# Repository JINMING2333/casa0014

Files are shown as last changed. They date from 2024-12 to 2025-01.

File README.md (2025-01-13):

# casa0014_LumiHealth
A device to monitor the health statues of users and create a comfortable light environment for them.
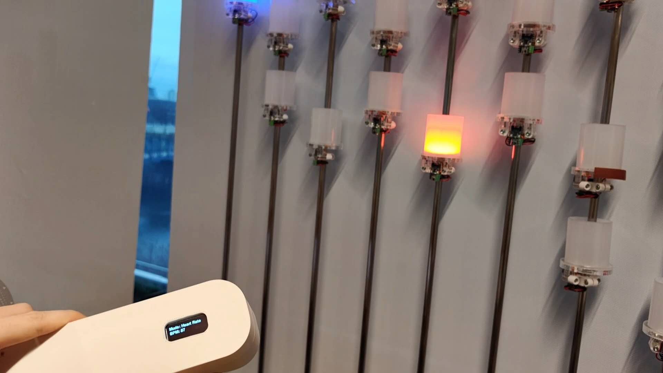
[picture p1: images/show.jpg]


## Inspiration
In the IoT market, smart home devices and wearable medical equipment have always been among the most popular areas. My design philosophy has always been centered on a people-oriented approach. A successful IoT device not only presents technical challenges but also requires careful consideration of social and user needs. During lectures, I learned that IoT devices can improve our quality of life in countless ways. However, the current IoT market has not met expectations or reached its full potential. I believe this is because many products fail to integrate seamlessly into people's daily lives and lack a truly user-centered design.

<table>
  <tr>
    <td align="center" width="33%">
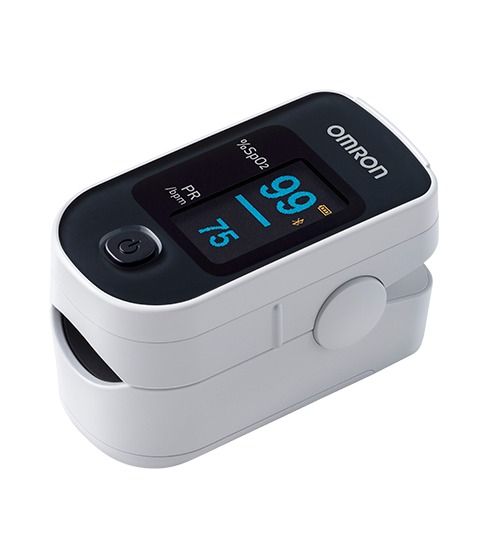
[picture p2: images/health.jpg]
Blood oxygen monitor
      <br/>
      <em>Fig.1 Blood oxygen monitor</em>
    </td>
    <td align="center" width="33%">
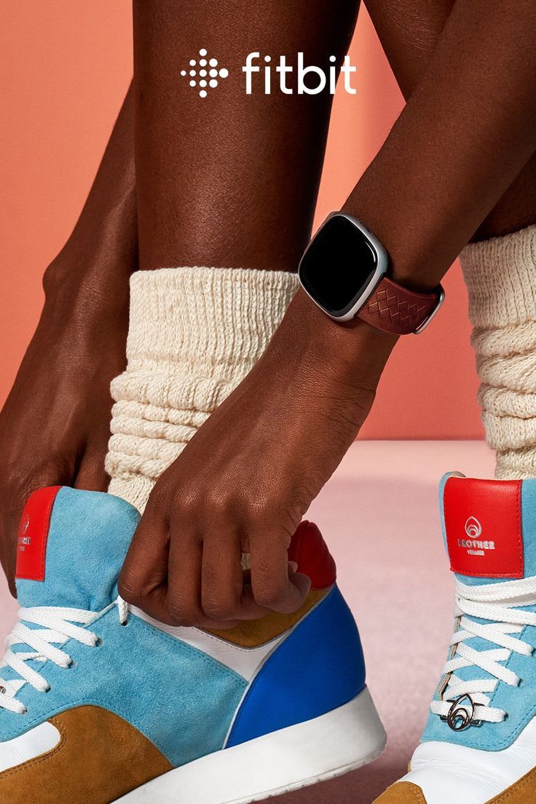
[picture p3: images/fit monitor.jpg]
Sports bracelet
      <br/>
      <em>Fig.2 Sports bracelet</em>
    </td>
    <td align="center" width="33%">
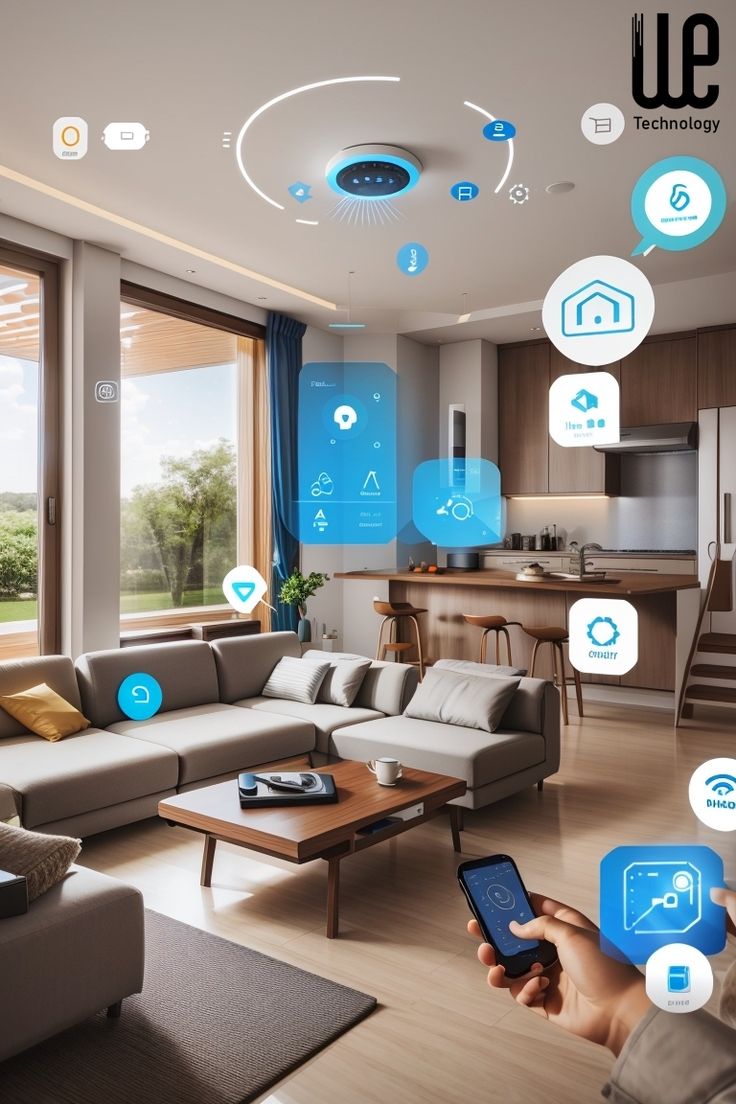
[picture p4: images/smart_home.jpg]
Smart Home Device
      <br/>
      <em>Fig.3 Smart Home Device</em>
    </td>
  </tr>
</table>

An IoT device, no matter how advanced its technological capabilities, cannot fulfill its purpose if users find it difficult or unappealing to use. This insight inspired me to design Lumi_Health, a health monitoring and environmental optimization system. Lumi_Health is dedicated to keeping users at the core of its design, aiming to enhance user experiences and improve quality of life through simplicity and accessibility.

### Current Application Scenarios
1) Medical Assistance
   Used for data collection and remote monitoring, when the patient's heart rate exceeds the normal threshold, the LED lights up red to alarm.
2) Fitness Tracking
   Use LED to indicate exercise intensity, such as blue means need to increase exercise intensity and red means reduce it.
3) Emotion Regulation
   Create a soothing environment through warm and cool tones or breathing light effects to help users relax.

## Design modes
1) Health status monitor mode: LED color changes can reflect different heart rate ranges.
   1) Blue indicates a lower heart rate(40-60 BPM).
   2) Yellow indicates a normal heart rate(60-85 BPM).
   3) Red indicates a high heart rate(85-120 BPM).
2) Relaxation mode: Adjust the lighting according to different body temperature ranges to create a relaxing atmosphere.
   1) when temperature is low, LED shows warm color breathing effect. 
   2) When temperature is high, LED shows cool color breathing effect;
   
PS: Switch mode by taping the surface of the sensor(when my finger approaches the sensor, the infrared reflection value changes greatly).

## System architecture
The operation of the whole project:
1) Make ensure the operating environment(connect WIFI and MQTT) is set up first;
2) Select the mode;
3) Read the data through the sensor, and then run different functions under the corresponding mode;
4) Publish and subscribe pixel topics through MQTT, update the light status, and realize remote operation.

MAX30102 sensor -> Arduino MKR 1010 -> WIFI -> MQTT broker -> LEDs

# Hardware settings
## Components

<table>
  <tr>
    <th width="15%">Component</th>
    <th width="20%">Image</th>
    <th width="25%">Function</th>
    <th width="25%">Wiring</th>
    <th width="15%">Library</th>
  </tr>
  <tr>
    <td>MAX30102 Sensor</td>
    <td align="center">
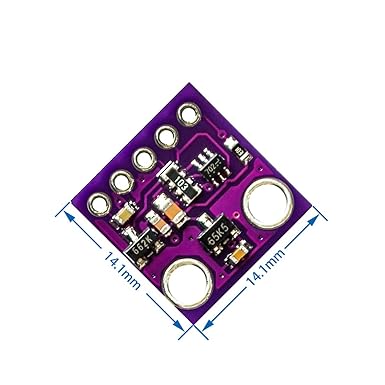
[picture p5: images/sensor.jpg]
MAX30102 Sensor
      
    </td>
    <td>
      - Heart rate monitoring<br/>
      - Blood oxygen level detection<br/>
      - Temperature sensing<br/>
      - IR reflection value measurement
    </td>
    <td>
      - VIN → 3.3V<br/>
      - GND → GND<br/>
      - SCL → SCL<br/>
      - SDA → SDA
    </td>
    <td>
      - SparkFun MAX3010x library<br/>
      - Wire.h
    </td>
  </tr>
  <tr>
    <td>OLED Display</td>
    <td align="center">
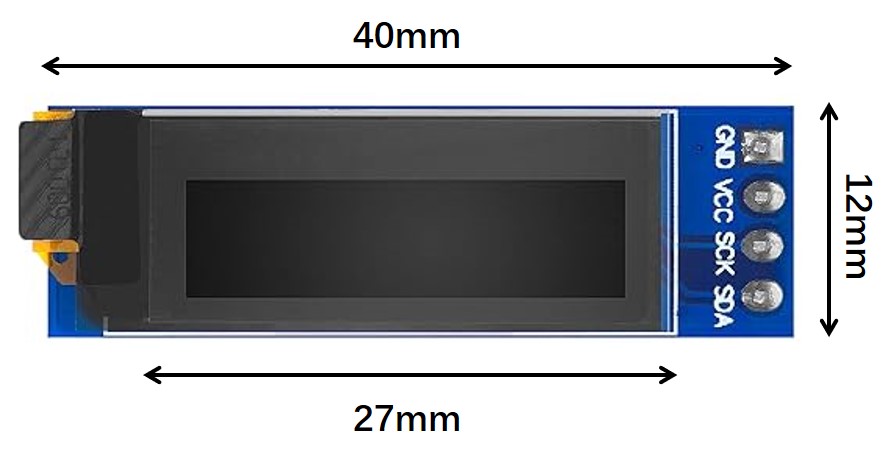
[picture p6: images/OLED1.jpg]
OLED Display
      
    </td>
    <td>
      - Real-time data display<br/>
      - Mode status indication<br/>
    </td>
    <td>
      - VCC → 3.3V<br/>
      - GND → GND<br/>
      - SCL → SCL<br/>
      - SDA → SDA
    </td>
    <td>
      - Adafruit_SSD1306<br/>
      - Adafruit_GFX
    </td>
  </tr>
</table>

## Wiring
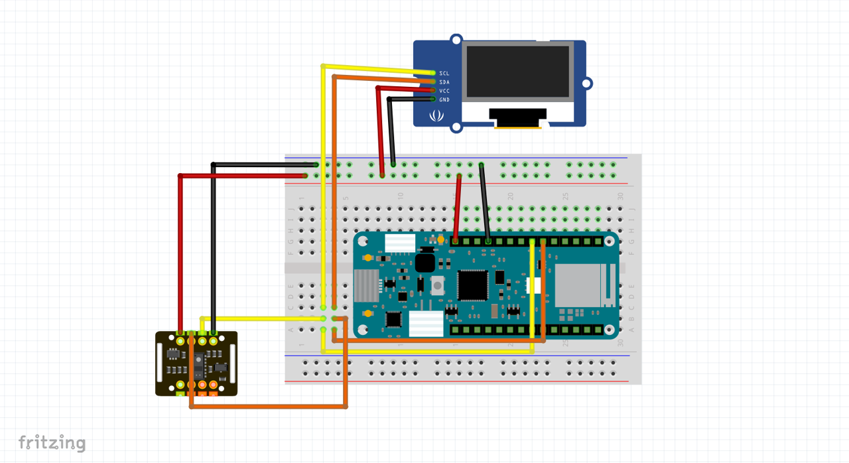
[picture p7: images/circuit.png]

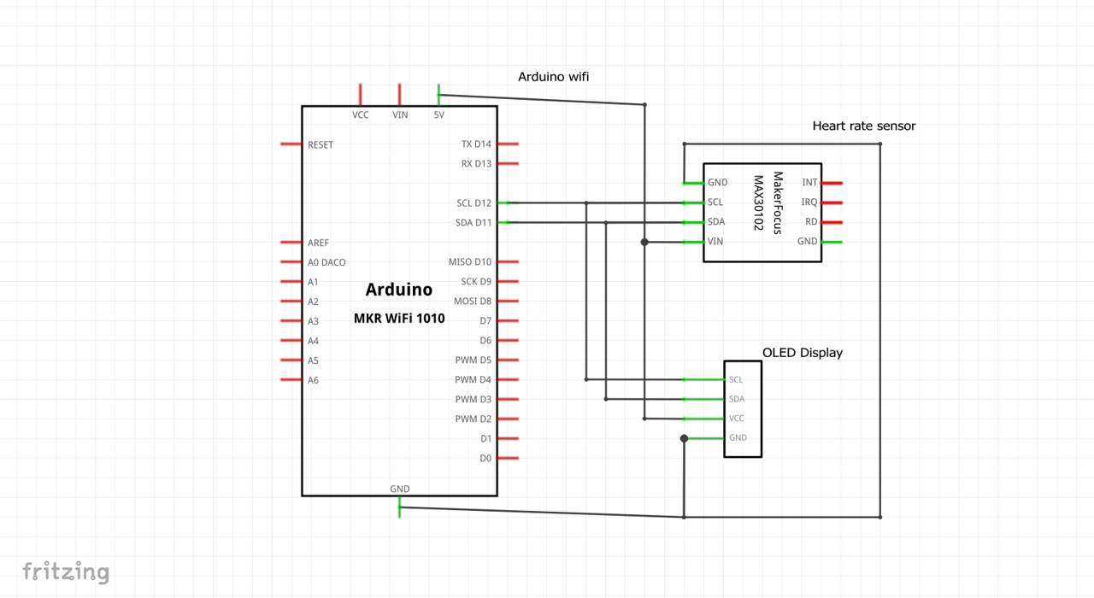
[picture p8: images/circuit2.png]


## Enclosure
The development of the device's casing was also an iterative process. During the early testing phase, a permanent casing was unnecessary and would have hindered quick adjustments and design iterations. Therefore, I initially used simple cardboard boxes as makeshift casings to facilitate rapid prototyping and modifications.

<table>
  <tr>
    <td align="center" width="33%">
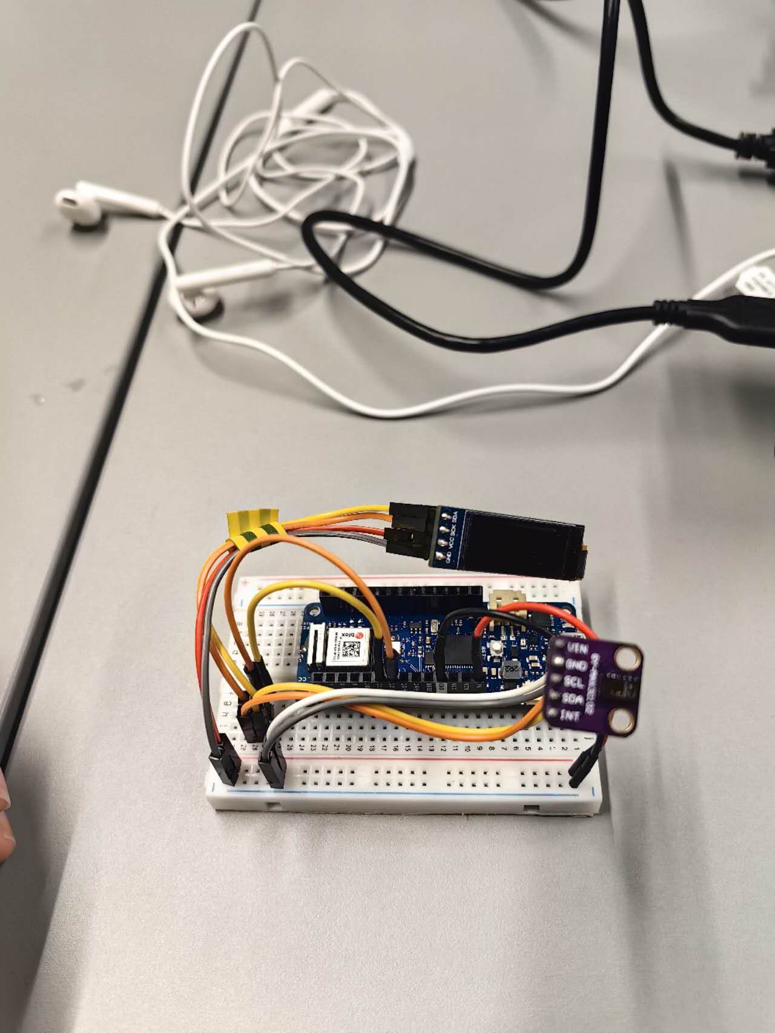
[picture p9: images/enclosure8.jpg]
      
    </td>
    <td align="center" width="33%">
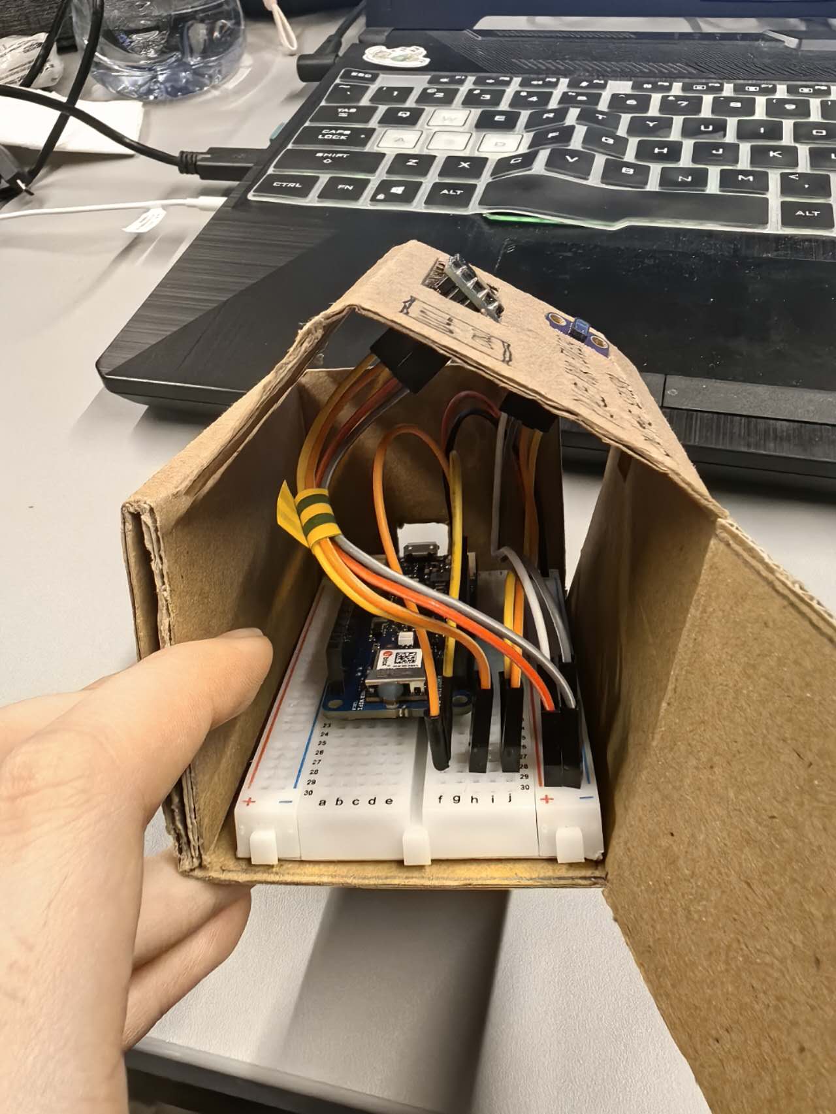
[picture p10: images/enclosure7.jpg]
      
    </td>
    <td align="center" width="33%">
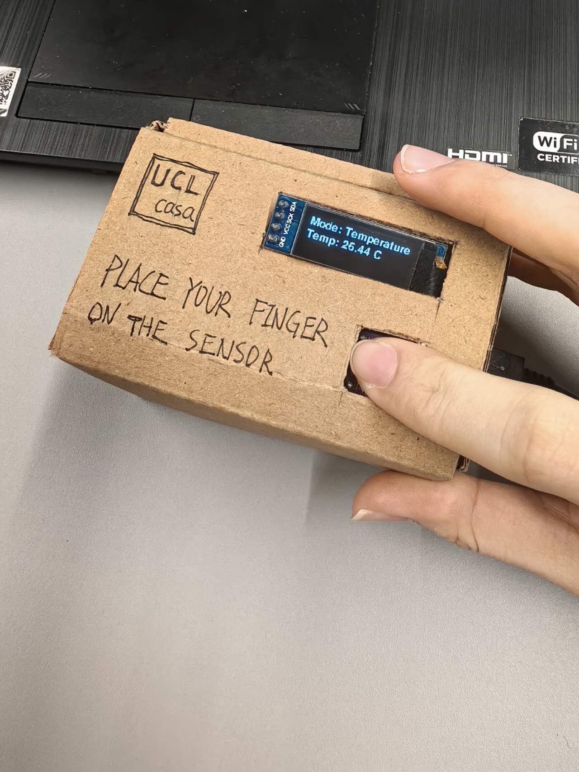
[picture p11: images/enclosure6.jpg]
      
    </td>
  </tr>
</table>
<p align="center"><em>simple cardboard box</em></p>

As the project progressed and the functions stabilized, it became time to formally consider the casing design. Drawing inspiration from the sleek and ergonomic form of a thermometer, I began creating a modeled design that balanced aesthetics, usability, and practicality. This approach ensured the final casing not only complemented the device’s functionality but also provided a user-friendly experience.

<table>
  <tr>
    <td align="center" width="25%">
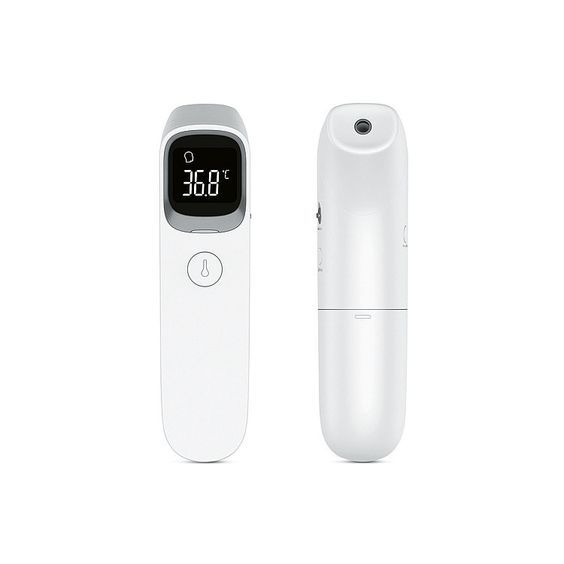
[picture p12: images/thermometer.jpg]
      <br/>
      <em>Fig.1 Inspiration-Thermometer</em>
    </td>
    <td align="center" width="25%">
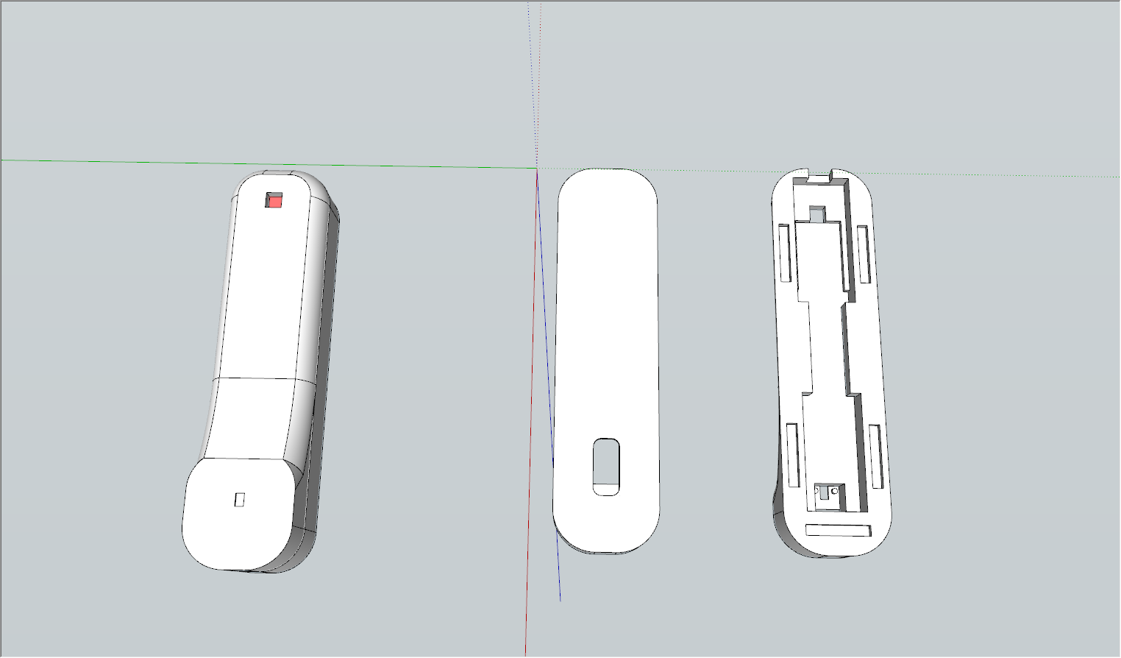
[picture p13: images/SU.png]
      <br/>
      <em>Fig.2 3D Model</em>
    </td>
    <td align="center" width="25%">
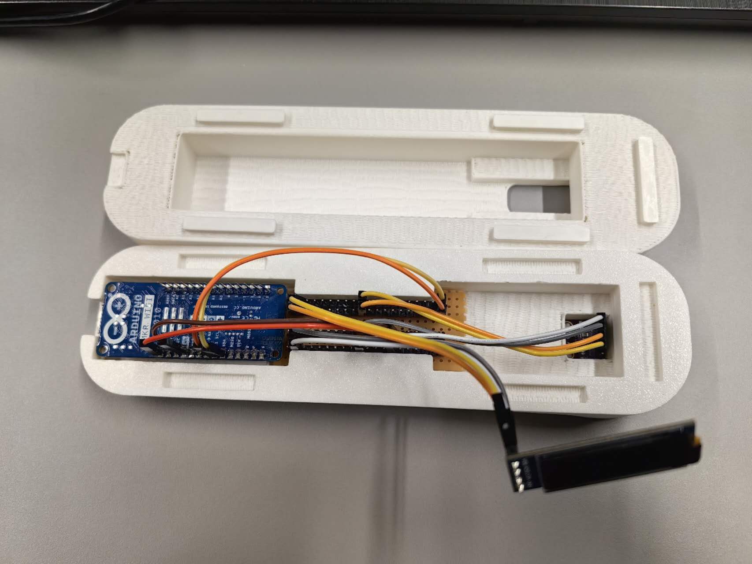
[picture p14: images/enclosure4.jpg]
      <br/>
      <em>Fig.3 Build Up</em>
    </td>
    <td align="center" width="25%">
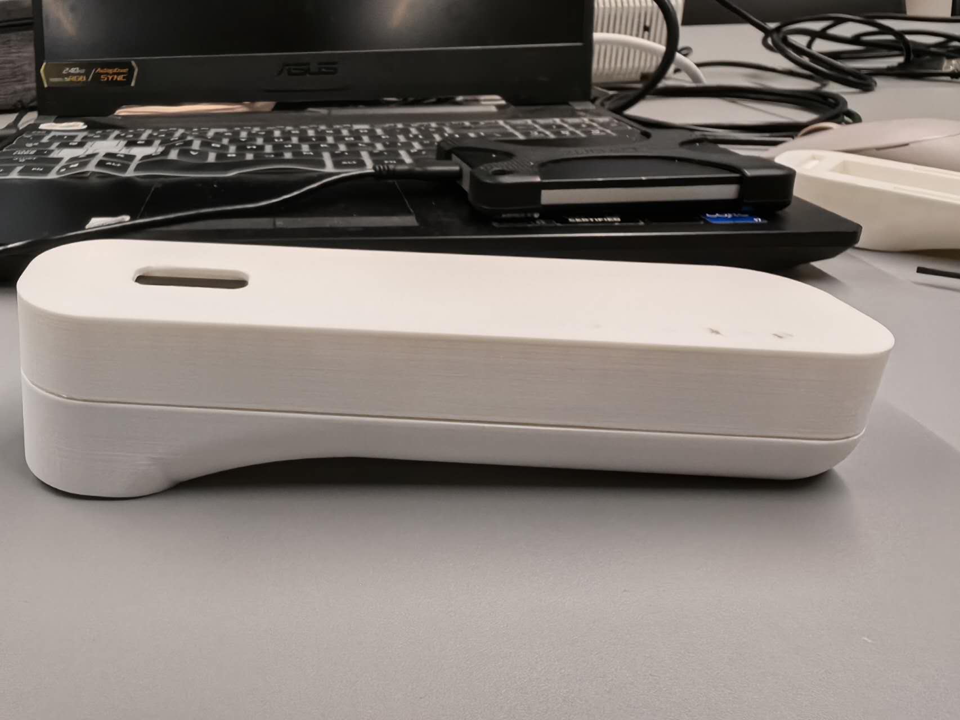
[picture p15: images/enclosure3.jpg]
      <br/>
      <em>Fig.4 Final Assembly</em>
    </td>
  </tr>
</table>

# Software setup
## Code testing
In the process of designing and writing the code for this project, I started from the demand analysis and gradually conceived the architecture and implementation of the entire system. First, the core function of the project was clarified, that is, real-time monitoring of heart rate and body temperature through the MAX30102 sensor, and intuitive visual feedback through the OLED display and RGB lights, while realizing network publishing and control of data through the MQTT protocol. To this end, I designed the following modules in stages:

1) Hardware initialization and function integration:
   I initialized the sensor (MAX30102) and the display (SSD1306 OLED) to ensure that they can work properly. And the heart rate was extracted by analyzing the photoelectric signal, and the temperature data was collected.

2) Mode switching and interactive control:
   On this basis, in order to enhance the user experience, I designed to switch the monitoring mode (heart rate and temperature) through touch operation. This function is realized by detecting the change of infrared light reflection, combined with the judgment logic of anti-shake and short and long press.

3)Visual effects and real-time updates:
   To improve the visual performance, I wrote a breathing light effect based on heart rate and temperature, and updated the light status to external devices in real time through the MQTT protocol. In addition, I optimized the refresh rate of the OLED display content so that users can get data updates at an appropriate frequency.

## Data visualization
In the process of testing, the serial port monitor of Arduino IDE is used to monitor the running status of the system in real time, which can assist debugging and optimization. 

<table>
  <tr>
    <td align="center" width="33%">
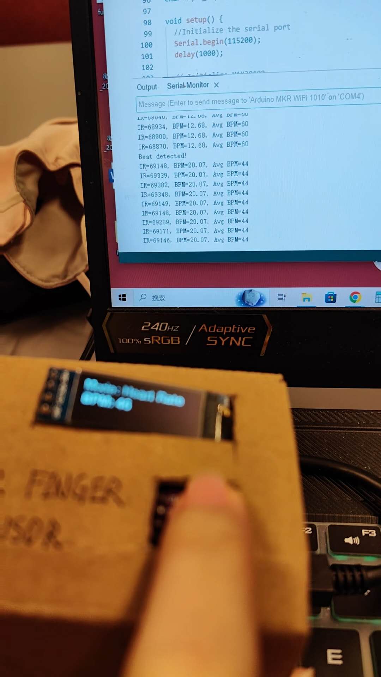
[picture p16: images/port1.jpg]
      <br/>
      <em>Fig.1 It takes a long time to obtain stable data</em>
    </td>
    <td align="center" width="33%">
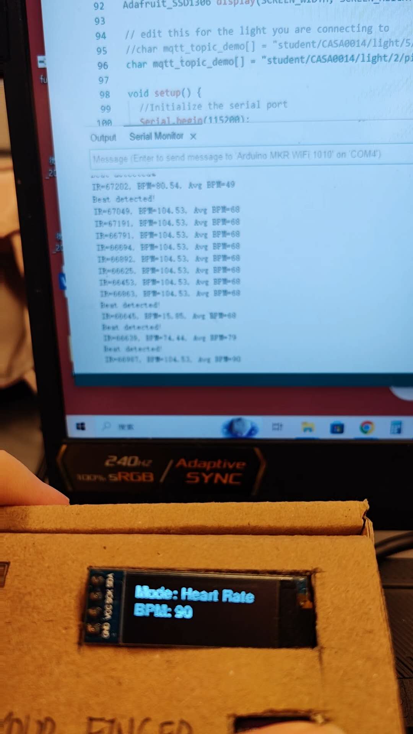
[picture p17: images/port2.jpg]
      <br/>
      <em>Fig.2 Real-time heart rate</em>
    </td>
    <td align="center" width="33%">
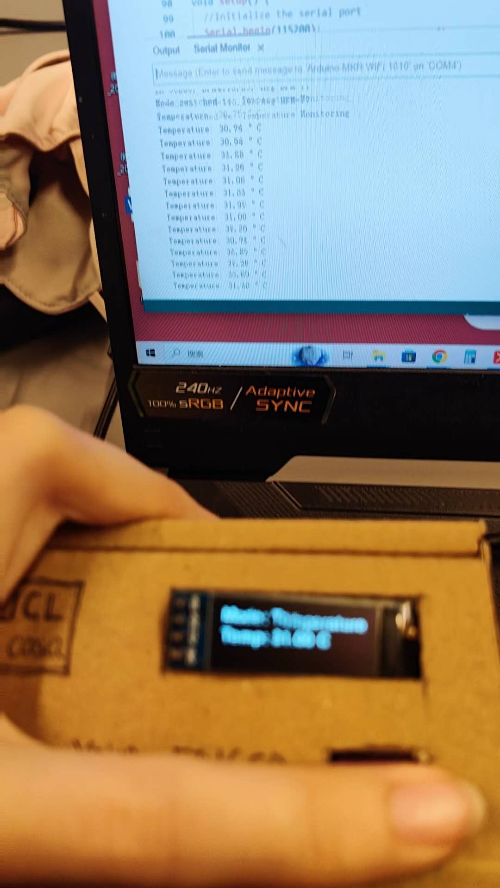
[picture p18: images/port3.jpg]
      <br/>
      <em>Fig.3 Read Temperature</em>
    </td>
  </tr>
</table>

# Achievements
https://github.com/user-attachments/assets/67e5ef44-76ce-48d3-a4db-6cb20c57eb6c

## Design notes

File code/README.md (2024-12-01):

There are reference code, local test version, network test version and integrated version.

## some mistakes
Q1: I defined a new topic to control the lights. I could see the messages I published in MQTT Explorer, but the lights didn't change.

A: Subscribers can only receive the messages that are published to a topic they have set.

## some challenges
Q1: In order to obtain more accurate heart rate values, the sensor must be sampled at a high frequency. However, if the sampling frequency is too fast, the reading will be too fast. If delay() is added, it will take a long time to obtain data.

A：Use millis() instead of delay() to control the time interval of data collection without blocking other tasks in the main loop.

Q2: After adding the OLED display, the sensor can no longer calculate the heart rate properly.

A: OLED and sensor share an I2C wire, and the refresh of OLED screen interferes with the heart rate detection of sensor.
1)Introduce time interval to separate the update of OLED and sensor;
2)Reduce the refresh frequency of OLED and increase the sampling frequency of sensor.

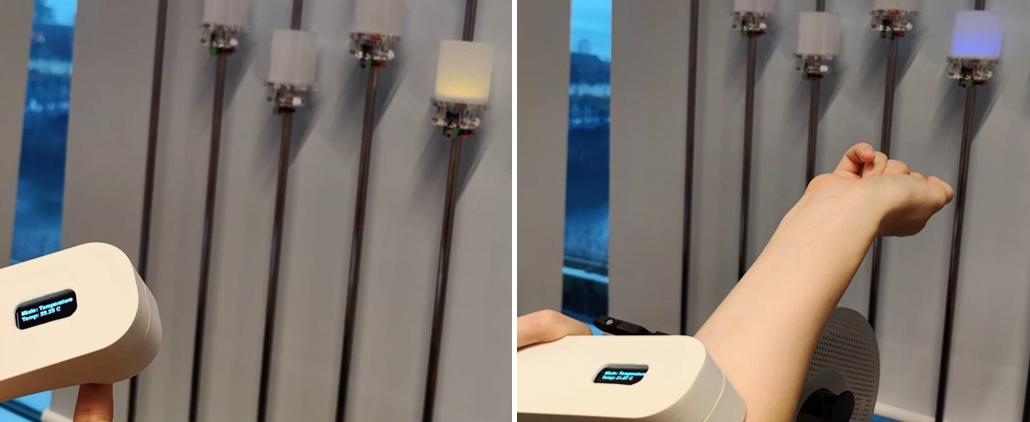
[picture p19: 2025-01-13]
images/final_play2.png

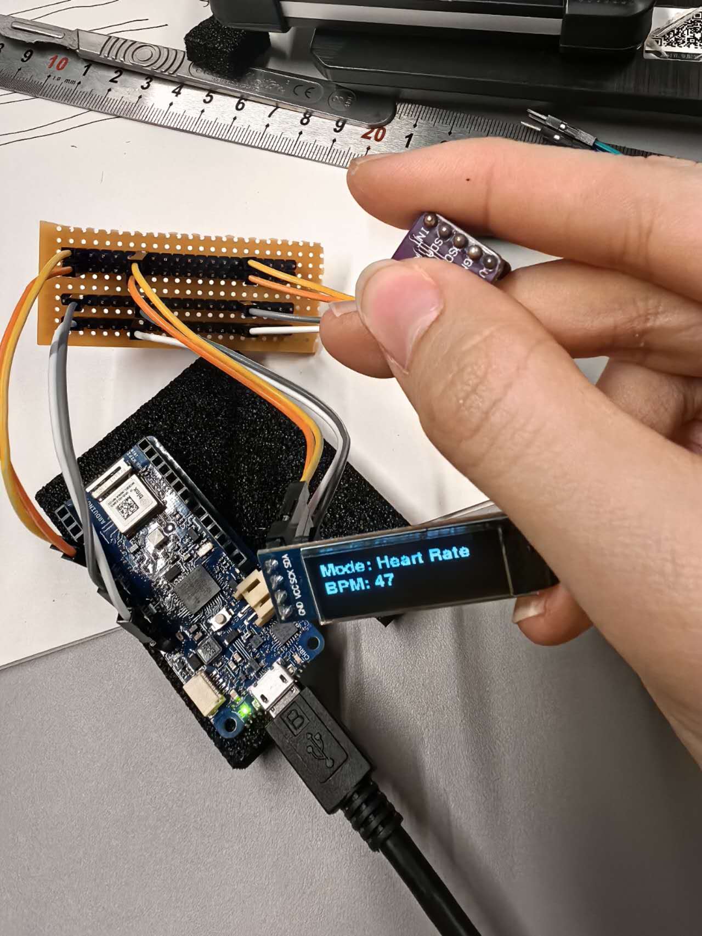
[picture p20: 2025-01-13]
images/process.jpg

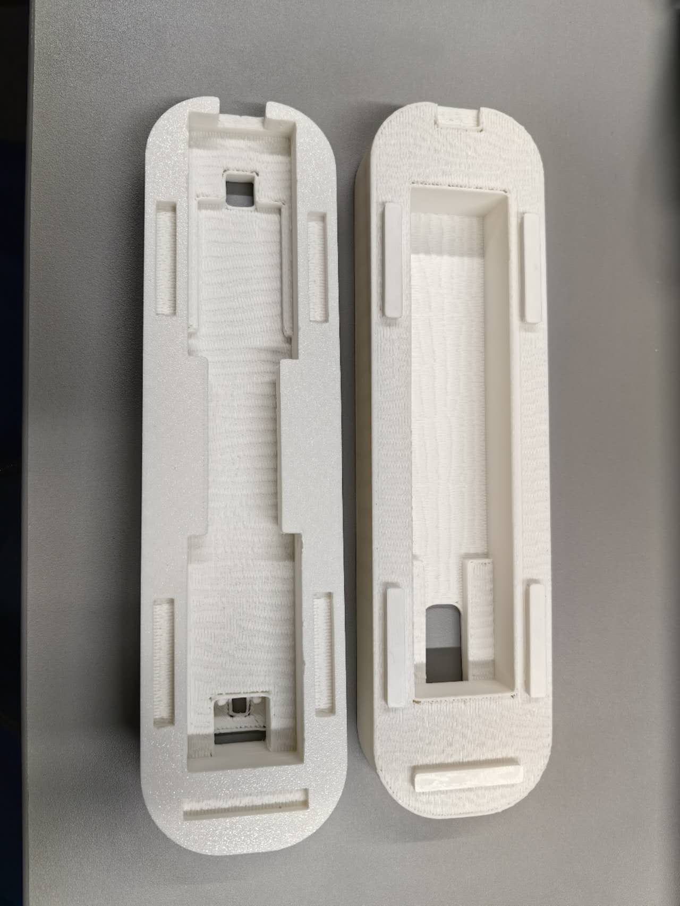
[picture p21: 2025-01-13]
images/enclosure5.jpg

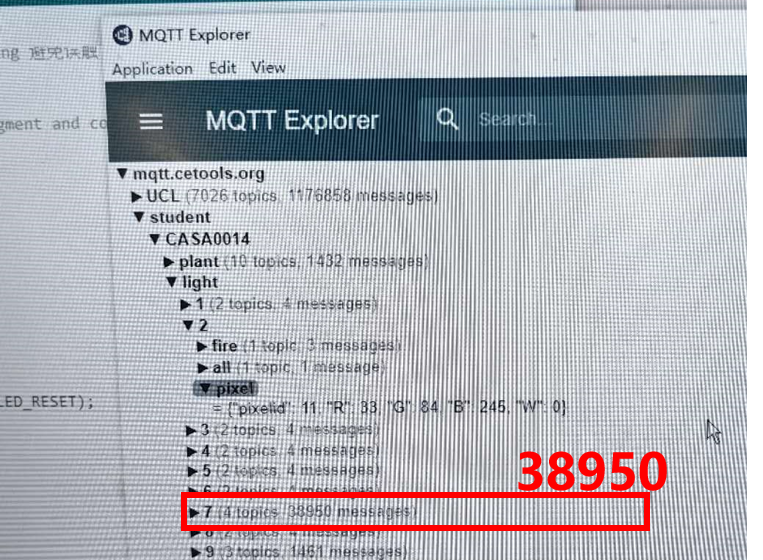
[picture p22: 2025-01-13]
images/data1.png

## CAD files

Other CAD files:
model/final.skp

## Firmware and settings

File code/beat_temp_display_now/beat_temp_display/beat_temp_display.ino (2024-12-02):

/* 

Heartbeat breathing light based on Chrono Lumina Blinker example for MKR1010

*/

// library
#include <WiFiNINA.h>   
#include <PubSubClient.h>  // library to connect MQTT
#include <utility/wifi_drv.h>   // library to drive to RGB LED on the MKR1010
#include "arduino_secrets.h" 

#include <Wire.h>   // library to support I2C communication
#include "MAX30105.h"    // SparkFun MAX30102 library
#include "heartRate.h"

#include <Adafruit_GFX.h>
#include <Adafruit_SSD1306.h>
#include "FreeSansBold7pt7b.h"

/*
**** please enter your sensitive data in the Secret tab/arduino_secrets.h
**** using format below

#define SECRET_SSID "ssid name"
#define SECRET_PASS "ssid password"
#define SECRET_MQTTUSER "user name - eg student"
#define SECRET_MQTTPASS "password";
 */

const char* ssid          = SECRET_SSID;
const char* password      = SECRET_PASS;
const char* mqtt_username = SECRET_MQTTUSER;
const char* mqtt_password = SECRET_MQTTPASS;  
const char* mqtt_server = "mqtt.cetools.org";  //MQTT server address
const int mqtt_port = 1884;
//const char*: store read-only strings, immutable;
//const int: store read-only integer values, immutable;
//int: store integer values, mutable;
//float: store decimals, mutable;

int status = WL_IDLE_STATUS;     // the Wifi radio's status
WiFiServer server(80);
WiFiClient wificlient;

//Manage MQTT message publishing and subscription
WiFiClient mkrClient;
PubSubClient client(mkrClient);

// MAX30102 setup
MAX30105 particleSensor;
const byte RATE_SIZE = 4; //Increase this for more averaging. 4 is good.
byte rates[RATE_SIZE]; //Array of heart rates
byte rateSpot = 0;
long lastBeat = 0; //Time at which the last beat occurred
//byte: a data type 0-255
//long: a time value

float currentBPM;
float temperature = 0.0;
int beatAvg;
int heartRate;

// control the printing of data once per second
unsigned long lastPrintTime = 0; 
const unsigned long printInterval = 500; // Serial monitor print interval
// Control the LED update frequency
unsigned long lastLedUpdateTime = 0;  
const unsigned long ledUpdateInterval = 1000; 
//unsigned long: store non-negative integer values, reinitialized each time they are used 每次使用重新初始化
//static: Used for variables that need to remember the state in the function, such as recording the last call time; Initialize once, retain value between function calls

// Click to switch control mode
bool clickDetected = false; // Detect if click occurs
unsigned long lastTapTime = 0; 
const unsigned long tapInterval = 500; // tap maximum interval time
const unsigned long debounceTime = 200; // prevent false triggering 避免误触
int mode = 0; // 0: heartbeat, 1: temperature
bool tapState = false; 
//bool: a data type, only true or false, Used in conditional judgment and control structures

// gradient control
int warmRed = 255;     
int warmGreen = 100;   
int warmBlue = 0;      
bool greenIncreasing = true; //Green channel increment sign

// OLED display setup
#define SCREEN_WIDTH 128
#define SCREEN_HEIGHT 32
#define OLED_RESET    -1
Adafruit_SSD1306 display(SCREEN_WIDTH, SCREEN_HEIGHT, &Wire, OLED_RESET);

// edit this for the light you are connecting to 
//char mqtt_topic_demo[] = "student/CASA0014/light/5/pixel/";
char mqtt_topic_demo[] = "student/CASA0014/light/16/pixel/";

void setup() {
  //Initialize the serial port
  Serial.begin(115200);
  delay(1000);

  // Initialize MAX30102
  if (!particleSensor.begin(Wire, I2C_SPEED_FAST)) {
    Serial.println("MAX30102 not detected. Check connections!");
    while (1);
  }
  Serial.println("Place your index finger on the sensor with steady pressure.");
  
  particleSensor.setup();  // Initialize the sensor with default values
  particleSensor.setPulseAmplitudeRed(0x3F); //Turn Red LED to low to indicate sensor is running
  particleSensor.setPulseAmplitudeIR(0x3F); 
  particleSensor.setPulseAmplitudeGreen(0); //Turn off Green LED
  particleSensor.enableDIETEMPRDY(); //Enable the temp ready interrupt.
  particleSensor.setSampleRate(100);         // increase sample rate
  particleSensor.setFIFOAverage(4);          // avg 4 samples
  particleSensor.enableFIFORollover();       // Avoid Data Loss
  Serial.println("Sensor Initialized");
  
  // Initialize OLED
  if(!display.begin(SSD1306_SWITCHCAPVCC, 0x3C)) {
    Serial.println(F("SSD1306 allocation failed"));
    while (1); {
      delay(1000); 
    }
  }
  display.clearDisplay();  
  display.setTextSize(1);  
  display.setTextColor(SSD1306_WHITE);  
  display.setFont(&FreeSansBold7pt7b);
  display.setCursor(0,10);
  display.println(F("Hello ~"));
  display.setCursor(0,26);
  display.println(F("LumiHealth!"));
  display.display();  // display content

  //Initialize WIFI&MQTT
  WiFi.setHostname("Lumina ucbvjx4");
  startWifi();
  client.setServer(mqtt_server, mqtt_port);

  Serial.println("setup complete");
}

void loop() {
  // we need to make sure the arduino is still connected to the MQTT broker
  // otherwise we will not receive any messages
  if (!client.connected()) {
    reconnectMQTT();
  }
  if (WiFi.status() != WL_CONNECTED) {
    startWifi();
  }
  client.loop();
  
  static unsigned long lastSensorRead = 0;
  if (millis() - lastSensorRead >= 10) { // read data every 10ms
    lastSensorRead = millis();

  //different mode set
  long irValue = particleSensor.getIR();
  if (irValue < 50000) { 
        temperature = 0.0; 
        heartRate = 0;     
        updateOLED("No Finger", 0); 
        sendMQTTEffect(0, 0, 0, 0); 
    } else {
        if (mode == 0) {
          heartbeat();  
        } else if (mode == 1) {
          monitorTemperature();
        }
    }
  }
  static unsigned long lastOLEDUpdate = 0;
  if (millis() - lastOLEDUpdate >= 1000) { // update OLED every sec
    lastOLEDUpdate = millis();
    updateOLED(mode == 0 ? "Heart Rate" : "Temperature", 
              mode == 0 ? heartRate : temperature);
  }

  // Detect click to switch mode
  detectClick();   
}

void detectClick() {
  long irValue = particleSensor.getIR();  //get reflectance value of infrared light
  unsigned long currentTime = millis();  //millis(): Returns the time since the device was started

  // detect touch(ir && not detect touch before && the interval between double touch > debounceTime)
  if (irValue > 60000 && !tapState && currentTime - lastTapTime > debounceTime) {
    tapState = true; 
    lastTapTime = currentTime;  //Update lastTapTime
  }

  // detect release(ir && detect touch before)
  if (irValue < 50000 && tapState) {
    tapState = false; 

    // detect click(the interval between release and touch < tapInterval)
    if (currentTime - lastTapTime < tapInterval) {
      mode = (mode == 0) ? 1 : 0; // change mode
      Serial.print("Mode switched to: ");
      Serial.println(mode == 0 ? "Heart Rate Monitoring" : "Temperature Monitoring");
    }
    lastTapTime = currentTime;
  }
}

void updateOLED(const char* modeText, float value) {
    display.clearDisplay(); 
    display.setCursor(0, 10); 

    // display the name of mode
    display.print("Mode: ");
    display.println(modeText);

    if (value == 0) { 
        display.setCursor(0, 26); 
        display.println("Value: N/A");
    } else {
        if (strcmp(modeText, "Heart Rate") == 0) {
            display.setCursor(0, 26); 
            display.print("BPM: ");
            display.println(heartRate);
        } else if (strcmp(modeText, "Temperature") == 0) {
            display.setCursor(0, 26); 
            display.print("Temp: ");
            display.print(temperature);
            display.println(" C");
        }
    }

    display.display(); 
}


void monitorTemperature() {
  // get temperature and ir
  temperature = particleSensor.readTemperature();
  long irValue = particleSensor.getIR();

  // Update temperature data once per second
  static unsigned long lastPrintTime = 0;
  if (millis() - lastPrintTime >= printInterval) {
    lastPrintTime = millis();
    if (irValue < 50000) { 
            temperature = 0.0; 
    }
    Serial.print("Temperature: ");
    Serial.print(temperature);
    Serial.println(" °C");
  }

  // Control LED
  if (irValue < 50000) {// Turn off all LED lights when no finger detected
    sendMQTTEffect(0, 0, 0, 0); 
  } else if (temperature > 33) {// coldcolor
    int R = random(0, 120);  
    int B = random(150, 255); 
    int G = random(50, 100);  
    int W = random(10, 80);
    sendMQTTEffect(R, G, B, W); 
    //sendMQTTEffect(0, 165, 255); // bluegreen
  } else {// warmcolor
    int R = random(200, 255); 
    int G = random(50, 150);  
    int B = random(0, 50);    
    int W = random(10, 80);  
    sendMQTTEffect(R, G, B, W);
    // if (greenIncreasing) {
    //   warmGreen += 5; 
    //   if (warmGreen >= 200) {
    //     greenIncreasing = false; 
    //   }
    // } else {
    //   warmGreen -= 5; 
    //   if (warmGreen <= 100) {
    //     greenIncreasing = true; 
    //   }
    // }

    // sendMQTTEffect(warmRed, warmGreen, warmBlue, 50); 
  }
}

void heartbeat(){
  // get ir value
  long irValue = particleSensor.getIR();

  static long smoothedIR = 0;
  static long previousIR = 0;
  smoothedIR = (smoothedIR * 0.95) + (irValue * 0.05); 
  long deltaIR = smoothedIR - previousIR;            
  previousIR = smoothedIR;

  // // ir
  // Serial.print("Raw IR Value: ");
  // Serial.print(irValue);
  // Serial.print(", Smoothed IR Value: ");
  // Serial.print(smoothedIR);
  // Serial.print(", IR Delta: ");
  // Serial.println(deltaIR);

  // Check for a heartbeat
  if (checkForBeat(irValue)== true) {
    Serial.println("Beat detected!");
    long delta = millis() - lastBeat; //Calculate interval between the current and previous heartbeat
    lastBeat = millis();

    currentBPM = 60 / (delta / 1000.0);

    // Filter abnormal BPM
    if (currentBPM > 20 && currentBPM < 255) {//Store BPM value in the array rates and loop over it
      rates[rateSpot++] = (byte)currentBPM; 
      rateSpot %= RATE_SIZE;              

      // Calculate average BPM
      beatAvg = 0;
      for (byte x = 0; x < RATE_SIZE; x++) {
        beatAvg += rates[x];
  
      }
      beatAvg /= RATE_SIZE;
      
      heartRate = beatAvg; // Updated value for LED control
    }
  }

  // // 添加 Avg Delta 计算
  // static long deltaSum = 0;
  // static int deltaCount = 0;

  // deltaSum += abs(deltaIR);
  // deltaCount++;

  // if (millis() % 1000 < 10) { // 每秒输出一次
  //   Serial.print("Avg Delta: ");
  //   Serial.println(deltaSum / deltaCount);
  //   deltaSum = 0;
  //   deltaCount = 0;
  // }

  if (millis() - lastPrintTime >= printInterval) {
    lastPrintTime = millis();
    Serial.print("IR=");
    Serial.print(irValue);
    Serial.print(", BPM=");
    Serial.print(currentBPM);
    Serial.print(", Avg BPM=");
    Serial.print(beatAvg);

    if (irValue < 50000) {
      Serial.print(" No finger?");
    }

    Serial.println();
  }

  //Update LED status every second
  static unsigned long lastLedUpdateTime = 0;
  if (millis() - lastLedUpdateTime >= ledUpdateInterval) {
    lastLedUpdateTime = millis();
    // Serial.print("heartRate=");
    // Serial.print(heartRate);

  if (irValue < 50000) {
      sendMQTTEffect(0, 0, 0, 0); 
  } else if (heartRate >= 95 && heartRate <= 120) {
      sendMQTTEffect(255, 0, 0, 0); // Red light
    } else if (heartRate >= 70 && heartRate < 95) {
      sendMQTTEffect(255, 255, 0, 0); // yellow light
    } else if (heartRate >= 40 && heartRate < 70) {
      sendMQTTEffect(0, 0, 255, 0);  // blue light
    } else {
      sendMQTTEffect(0, 0, 0, 0); // Turn off the light
    } 
  }
}

void sendMQTTEffect(int R, int G, int B, int W) {
  char mqtt_message[100];
  for (int i = 0; i < 12; i++) { // Control all 12 LEDs
    sprintf(mqtt_message, "{\"pixelid\": %d, \"R\": %d, \"G\": %d, \"B\": %d, \"W\": 0}", i, R, G, B, W);
    delay(10); 
    
    if (client.publish(mqtt_topic_demo, mqtt_message)) {
      //Serial.println("Message published");
    } else {
      Serial.println("Failed to publish message");
    }
  }
}

void startWifi(){  
  // check for the WiFi module:
  if (WiFi.status() == WL_NO_MODULE) {
    Serial.println("Communication with WiFi module failed!");
    // don't continue
    while (true);
  }
  String fv = WiFi.firmwareVersion();
  if (fv < WIFI_FIRMWARE_LATEST_VERSION) {
    Serial.println("Please upgrade the firmware");
  }

  // Function for connecting to a WiFi network
  // is looking for UCL_IoT and a back up network (usually a home one!)
  int n = WiFi.scanNetworks();
  Serial.println("Scan done");
  if (n == 0) {
    Serial.println("no networks found");
  } else {
    Serial.print(n);
    Serial.println(" networks found");
    // loop through all the networks and if you find UCL_IoT or the backup - ssid1
    // then connect to wifi
    Serial.print("Trying to connect to: ");
    Serial.println(ssid);
    for (int i = 0; i < n; ++i){
      String availablessid = WiFi.SSID(i);
      // Primary network
      if (availablessid.equals(ssid)) {
        Serial.print("Connecting to ");
        Serial.println(ssid);
        WiFi.begin(ssid, password);
        while (WiFi.status() != WL_CONNECTED) {
          delay(600);
          Serial.print(".");
        }
        if (WiFi.status() == WL_CONNECTED) {
          Serial.println("Connected to " + String(ssid));
          break; // Exit the loop if connected
        } else {
          Serial.println("Failed to connect to " + String(ssid));
        }
      } else {
        Serial.print(availablessid);
        Serial.println(" - this network is not in my list");
      }
    }
  }
  Serial.println("");
  Serial.println("WiFi connected");
  Serial.print("IP address: ");
  Serial.println(WiFi.localIP());
}

void reconnectMQTT() {
  if (WiFi.status() != WL_CONNECTED){
    startWifi();
  } else {
    //Serial.println(WiFi.localIP());
  }

  // Loop until we're reconnected
  while (!client.connected()) {    // while not (!) connected....
    Serial.print("Attempting MQTT connection...");
    // Create a random client ID
    String clientId = "LuminaSelector";
    clientId += String(random(0xffff), HEX);
    
    // Attempt to connect
    if (client.connect(clientId.c_str(), mqtt_username, mqtt_password)) {
      Serial.println("connected");
      // ... and subscribe to messages on broker
    } else {
      Serial.print("failed, rc=");
      Serial.print(client.state());
      Serial.println(" try again in 5 seconds");
      // Wait 5 seconds before retrying
      delay(5000);
    }
  }
}

void callback(char* topic, byte* payload, int length) {
  // Handle incoming messages
  Serial.print("Message arrived [");
  Serial.print(topic);
  Serial.print("]: ");
  for (int i = 0; i < length; i++) {
    Serial.print((char)payload[i]);
  }
  Serial.println();
}

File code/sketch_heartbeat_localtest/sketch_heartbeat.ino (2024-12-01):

#include <Wire.h>
#include "MAX30105.h"         // SparkFun MAX30102 库
#include <Adafruit_NeoPixel.h> // 灯带控制库

#define LED_PIN 6            // 灯带数据引脚
#define NUM_PIXELS 30        // 灯带上 LED 数量

MAX30105 particleSensor;
Adafruit_NeoPixel strip(NUM_PIXELS, LED_PIN, NEO_GRB + NEO_KHZ800);

unsigned long lastBeatTime = 0;   // 上一次心跳时间
float beatThreshold = 0;         // 动态心跳检测阈值
float irSignal = 0;              // 当前红外信号值
float previousSignal = 0;        // 上一次红外信号值
bool isBeat = false;             // 当前是否检测到心跳

void setup() {
  Serial.begin(115200);

  // 初始化灯带
  strip.begin();
  strip.show();  // 清除所有灯光
  strip.setBrightness(50); // 设置灯带亮度

  // 初始化 MAX30102
  if (!particleSensor.begin(Wire, I2C_SPEED_STANDARD)) {
    Serial.println("MAX30102 not detected. Check connections!");
    while (1);
  }
  particleSensor.setup(); // 默认传感器配置
  Serial.println("MAX30102 initialized.");

  // 初始化动态阈值
  beatThreshold = 50000; // 根据实际情况调整
}

void loop() {
  // 读取红外光信号
  irSignal = particleSensor.getIR();

  // 检测是否有手指接触
  if (irSignal < 50000) { // 红外信号小于阈值时表示未检测到手指
    Serial.println("No finger detected.");
    turnOffLED();
    delay(100);
    return;
  }

  // 检测心跳（简单波峰检测）
  if (irSignal > beatThreshold && irSignal > previousSignal) {
    // 如果当前信号大于动态阈值且是波峰，判断为一次心跳
    if (!isBeat) {
      isBeat = true; // 标记心跳
      unsigned long currentTime = millis();
      unsigned long beatDuration = currentTime - lastBeatTime;
      lastBeatTime = currentTime;

      // 计算心率（bpm）
      float heartRate = 60000.0 / beatDuration; // 每分钟跳动次数
      Serial.print("Heart Rate: ");
      Serial.print(heartRate);
      Serial.println(" bpm");

      // 控制灯带闪烁
      pulseLED();
    }
  } else if (irSignal < beatThreshold) {
    // 如果信号下降，心跳结束
    isBeat = false;
  }

  // 更新动态阈值
  beatThreshold = (beatThreshold * 0.9) + (irSignal * 0.1); // 平滑调整阈值
  previousSignal = irSignal; // 更新上一次信号值

  delay(20); // 稳定信号读取
}

// 灯带点亮
void pulseLED() {
  for (int i = 0; i < NUM_PIXELS; i++) {
    strip.setPixelColor(i, strip.Color(255, 0, 0)); // 红色灯光
  }
  strip.show();
  delay(100); // 保持亮一段时间

  // 关闭灯带
  turnOffLED();
}

// 灯带熄灭
void turnOffLED() {
  for (int i = 0; i < NUM_PIXELS; i++) {
    strip.setPixelColor(i, strip.Color(0, 0, 0)); // 关闭所有灯光
  }
  strip.show();
}

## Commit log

2025-01-13 sensor table
2025-01-13 add pictures
    [final.skp]
